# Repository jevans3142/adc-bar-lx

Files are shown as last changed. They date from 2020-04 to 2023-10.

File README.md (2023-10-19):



# ADC Theatre - Bar Lighting Controller

This repository hosts the software and hardware design for the [ADC Theatre's](https://www.adctheatre.com) bar lighting scene controller. The system is based around an ESP32 chip (using a development board typicaly found online as the DOIT board - 30 pin version, though as we are not using WiFi or Bluetooth etc the hardware could be easily adapted to another chip version) with DMX input and output, audio input for sound-to-light mode, and a remote scene set control panel.

## Features

* Provides seven reprogrammable scenes which can be faded between from the easy to use remote control panel
* DMX input for programming scenes with highest-takes-precedence merge function for operating a more complex show without recabling 
* Sound-to-light function for parties with four analogue filter channels to replicate an older system. Party functions can be enabled and disabled per scene
* Small OLED screen and menu system on the central rackmount controller for configuration
* In the event of power being disconnected the DMX input is directly connected to the output using relays to make bypass easy
* All scenes and settings are stored on an SD card

## Build

The microcontroller used is an ESP32. After standard installation of the esp-idf FreeRTOS toolchain, currently building on v5.1.1 as a stable version with the configuration included in the src folder (ie. when building do not run the idf.py set-target esp32 command as directed in the esp-idf Getting Started instructions to set up the default build config - just go straight to idf.py build)

## Hardware

PCB files in KiCAD format:
* Power supply
* Mainboard
* Sound-to-light
* Buttons (front panel)
* Remote control panel

In addition there are files for Schaeffer AG's FrontPanelDesigner application covering:
* Case including front and back panels
* Remote control panel

There are 3DM model files for two 3D printed elements: 
* A bracket to hold the OLED screen to the case frontpanel 
* A bracket to hold the SD card module to the case frontpanel

In addition to the standard components populating the PCBs one ESP32 'DOIT' style devboard, an SD card breakout module, and an OLED screen module are required, all purchased from eBay. Multiple spares are held of each item by John if required for the ADC.

## Copyright
Copyright (c) 2019-2022 John Evans and contributors.

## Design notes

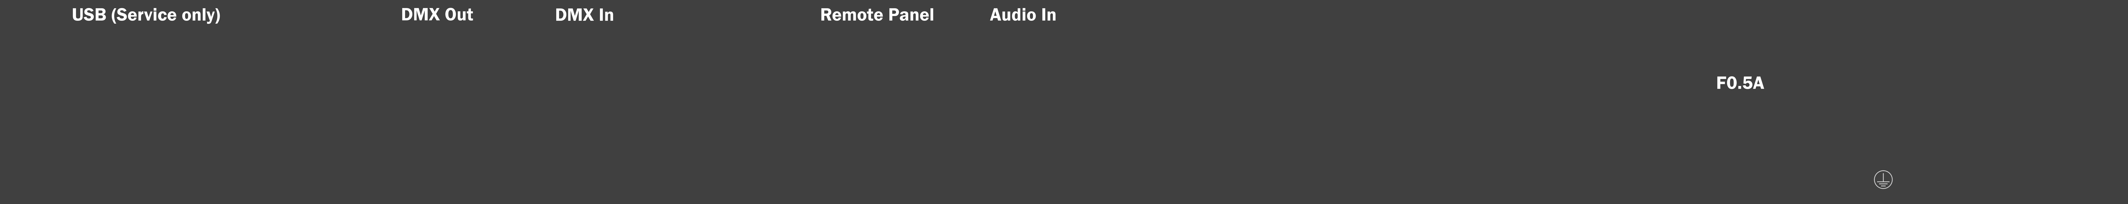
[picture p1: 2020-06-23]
hardware/case/backimg.png

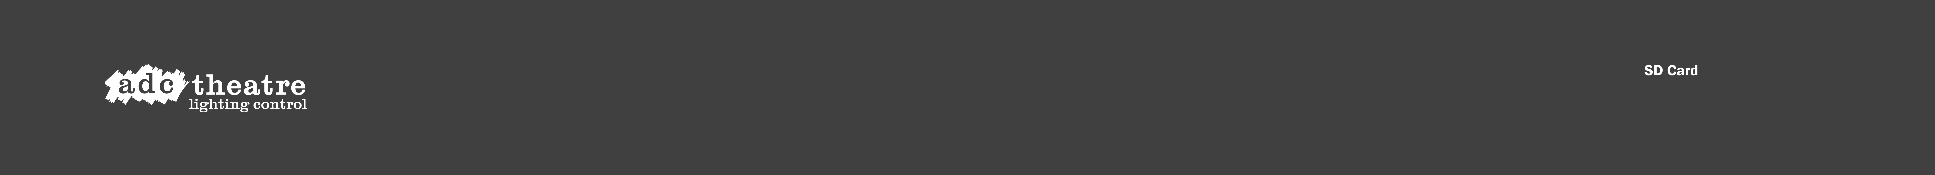
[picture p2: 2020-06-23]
hardware/case/frontimg.png

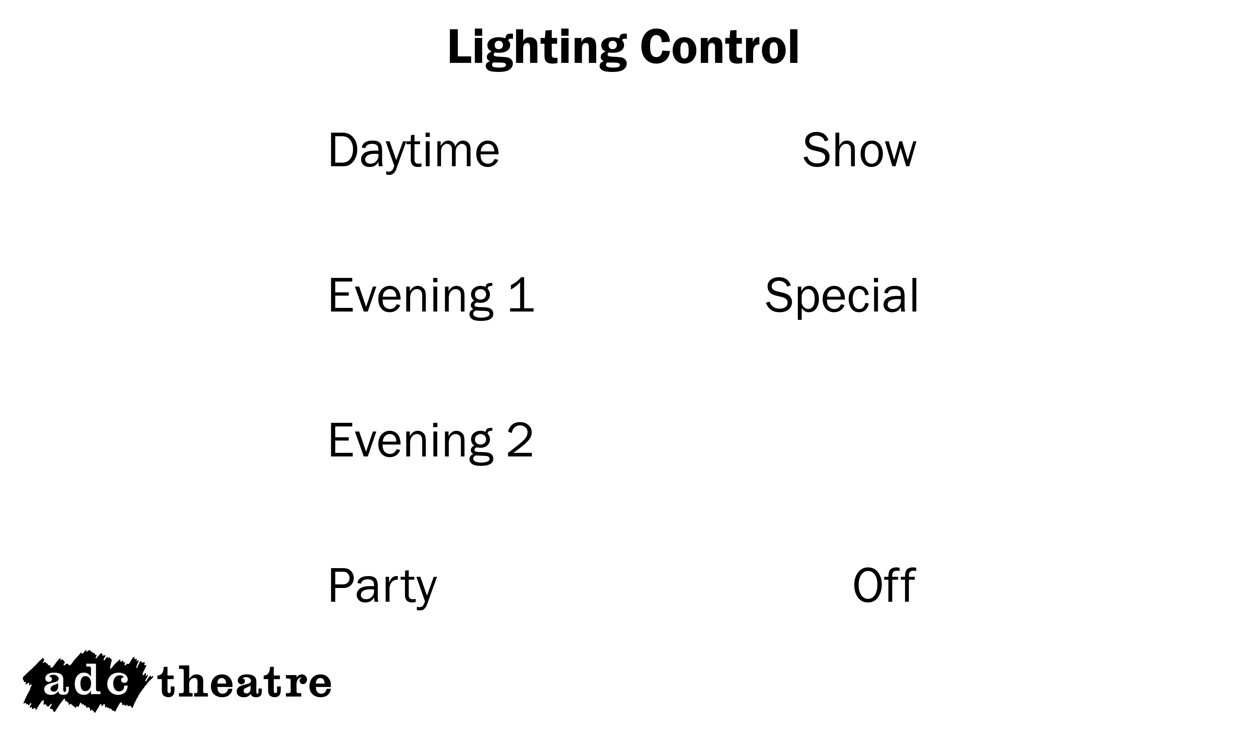
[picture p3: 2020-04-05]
hardware/control-panel-frontplate/Remotepanel.png

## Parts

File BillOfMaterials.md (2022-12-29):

# Bill of Materials - ADC Bar LX Controller

## Central Controller 
Unit is a 1U rackmount case with various PCBs inside, connectors on rear, display and user interface on front.

### Power Supply PCB
KiCAD PCB files found in hardware/psu-board
|References |Item |Package |Quantity|Value |Supplier and ref |
|---|---|---|---|---|---|
|PS1 |10W Switch mode PSU 230V->15V | |1 |RAC10-15DK/277  |RS 165-5098 |
|U1 |Switching regulator, 12V output | |1 |R-78E12-0.5 |RS 122-8230 |
|U2 |Switching regulator, 5V output | |1 |R-78E5.0-0.5 |RS 757-7239 |
|J1-J4 |4 pin 2.54mm pitch keyed connector  |2.54mm pitch |5 |Molex KK254 1x04|RS 792-2881 |
|C1,C2 |Capacitor - Electrolytic/Polarised  |2.5mm pitch  |2 |10uF |Generic |
### Main PCB
KiCAD PCB files found in hardware/main-board
|References |Item |Package |Quantity|Value |Supplier and ref |
|---|---|---|---|---|---|
|U7 |ESP32 dev board - ‘DOIT’ 30 pin type| |1 | |eBay - happybuddhatrading|
|J1, J2, J5x2 |Krone 4 pole IDC terminal | |4 | |Rapid 24-0610 |
|U3,U4 |Line Transceiver RS-422 |DIP-8 |2 |MAX485 |RS 540-2243 |
|C1,C2 |Capacitor - Unpolarised |5mm pitch |2 |470nF |Generic |
|C3 |Capacitor - Electrolytic/Polarised  |2.5mm pitch  |1 |10uF |Generic |
|J3, J4, J6, J7, J9|4 pin 2.54mm pitch keyed connector  |2.54mm pitch |5 |Molex KK254 1x04|RS 792-2881 |
|J8 |5 pin 2.54mm pitch keyed connector  |2.54mm pitch |1 |Molex KK254 1x04|RS 679-5599 |
|K1,K2 |DPDT Relay - 12V coil, non-latching | |2 | |RS 800-4441 |
|R1,R7 |0.25W resistor |10.16mm pitch|2 |470R |Generic |
|R2,R4,R5 |0.25W resistor |10.16mm pitch|3 |4.7Kohm |Generic |
|R3,R6 |0.25W resistor |10.16mm pitch|2 |120R |Generic |
|R8 |0.25W resistor |10.16mm pitch|1 |10Kohm |Generic |
|U1, U5 |DC-DC isolator 5V 1W | |2 | |RS 191-4922 |
|U2,U6 |Transistor output Optocoupler | |2 |6N137(F) |RS 625-7909 |
|- |8 pin DIP socket | |4 | |RS 674-2435 |
|- |15 pin socket (for dev board) | |2 | |RS 180-0452 |
### Sound-to-light PCB
KiCAD PCB files found in hardware/s2l-board
|References |Item |Package |Quantity|Value |Supplier and ref|
|---|---|---|---|---|---|
|C1,C2,C7,C11,C15 |Capacitor - Unpolarised |5mm pitch |5 |100nF |Generic |
|C3 |Capacitor - Unpolarised |2.5mm pitch  |1 |220pF |Generic |
|C4,C8,C12,C16 |Capacitor - Electrolytic/Polarised |1.5mm pitch  |4 |47uF |Generic |
|C5 |Capacitor - Unpolarised |5mm pitch |1 |10nF |Generic |
|C6 |Capacitor - Unpolarised |5mm pitch |1 |20nF |Generic |
|C9,C10,C13,C14,C17,C18|Capacitor - Unpolarised |5mm pitch |6 |100nF |Generic |
|D1,D3,D5,D7 |Signal diode |DO-35 |4 |1N4148 |Generic |
|D2,D4,D6,D8 |3V Zener Diode |DO-35 |4 |BZX79C3V0 |RS 544-3525 |
|J1-J3 |4 pin 2.54mm pitch keyed connector |2.54mm pitch |3 |Molex KK254 1x04|RS 792-2881 |
|R1,R8,R11,R12,R18,R27 |0.25W resistor |10.16mm pitch|6 |10Kohm |Generic |
|R2,R9 |0.25W resistor |10.16mm pitch|2 |6.8Kohm |Generic |
|R3 |0.25W resistor |10.16mm pitch|1 |3.3Kohm |Generic |
|R4 |0.25W resistor |10.16mm pitch|1 |100R |Generic |
|R5,R6 |0.25W resistor |10.16mm pitch|2 |100k |Generic |
|R7,R14,R15,R20,R25 |0.25W resistor |10.16mm pitch|5 |1Kohm |Generic |
|R10,R16,R21,R26 |0.25W resistor |10.16mm pitch|4 |2.2Kohm |Generic |
|R13,R22 |0.25W resistor |10.16mm pitch|2 |22Kohm |Generic |
|R17 |0.25W resistor |10.16mm pitch|1 |47Kohm |Generic |
|R19 |0.25W resistor |10.16mm pitch|1 |320R |Generic |
|R23 |0.25W resistor |10.16mm pitch|1 |4.7Kohm |Generic |
|R24 |0.25W resistor |10.16mm pitch|1 |220R |Generic |
|U1-U5 |Single audio op-amp |DIP-8 |5 |UA741CP |RS 305-311 |
|- |8 pin DIP socket | |5 | |RS 674-2435 |

### Buttons PCB
KiCAD PCB files found in hardware/menu-buttons
|References|Item |Package |Quantity|Value |Supplier and ref|
|---|---|---|---|---|---|
|SW1-SW4 |Tactile buttons,6x6mm,13mm high | |4 | |RS 479-1457 |
|J1 |5 pin 2.54mm pitch keyed connector|2.54mm pitch |1 |Molex KK254 1x05|RS 679-5599 |

Note that J1 is optional - wires can be soldered directly to the PCB to create a wiring harness. If so qty of 5 pin 2.54mm headers listed in 'Other' below is 1 not 2. 

### Case
The case was ordered using Front Panel Designer/Schaeffer AG. There are a number of source files for the Front Panel Designer software in hardware/case; in addition some hardware and side profile extrusions were ordered from Schaeffer at the same time. The part numbers given here are for Schaeffer's hardware parts.
- 1x Front panel (see FPD file)
- 1x Back panel (see FPD file)
- 1x Top panel (see FPD file)
- 1x Bottom panel (see FPD file)
- 2x GLGP1013 Side profiles (black anodised) - 195mm length
- 1x GGMS1122 Assembly kit ISP/B3.0-SW DIN7982 - black - consists of 8x CSK head screw 2.9mm diax9.5mm length and four rubber feet
- 1x GGWS0112 Housing bracket pack - consists of 8 L brackets
- 1x GGRB3306 Screw packet - M3x6mm CSK head machine screws 
Note that this ended up being a very, very expensive way of creating a case. There's likely some significant changes that could be made here.

### Connectors
- 1x 3D printed SD card holder - see 3dm file at hardware/sd-card-3dprint
- 1x SD card slot module - https://proto-pic.co.uk/product/sd-mmc-card-breakout-board
- 1x OLED screen module - 1.3" 128x64 OLED display I2C - eBay - karens_e-shop - https://www.ebay.co.uk/itm/282358769160
- 1x 3D printed SD card holder - see 3dm file at hardware/screen-holder-3dprint
- 1x Neutrik Powercon 20A inlet - NAC3MPXXA
- 1x Neutrik XLR-3F - NC3FDM3-L-1
- 3x 8P8C/RJ45 D type connectors - TUK D-SERIES KEYSTONE RJ45 IDC SOCKET Cat5E, tool-less, black - Canford 44-9121
- 1X USB passthrough D type - Neutrik NAUSB-W

### Other
- 1x SD card (>1MB free)
- Equipment wire and heatshrink for internal wiring
- 1.5mm Cu wiring and heatshrink for link from Powercon to PSU
- Crimp lugs for earthing of case and rear panel
- 1x Fuseholder - RS 563-784
- 1x Fuse - F0.5A LBC 5x20mm eg. RS 563-463
- 1x Powercon power cable
- Short length of audio cable (eg. Canford FST) for link from XLR to PCB
- 3x Short lengths of CAT5e cable for link from rear panel connectors to PCB
- 1x 30cm USB-A to mini-USB cable for programming port on ESP32 link to case 
- 9x 4 pin 2.54mm pitch keyed plugs to mate with PCB - Molex KK254 - RS 679-5388
- 1/2x 5 pin 2.54mm pitch keyed plugs to mate with PCB - Molex KK254 - 679-5385
- 44x (approx)  crimp contacts for connectors - Molex KK254 - RS 172-9178

## Control Panel
1x Control panel for remote control of scene states - technically this is optional
### PCB

KiCAD PCB files found in hardware/control-panel
 
|References|Item |Package |Quantity|Value |Supplier and ref|
|---|---|---|---|---|---|
|J1 |8P8C connector | |1 |8P8C |RS 331-6443 |
|SW1-SW7 |4 pin 2.54mm pitch keyed connector|2.54mm pitch |7 |Molex KK254 1x04|RS 792-2881 |
|Q1-Q7 |NPN transistor - KSP43BU |TO-92 |7 | |RS 806-4620 |
|R1-R15 |0.25W resistor |10.16mm pitch |15 |4.7Kohm |Generic |
|C1 |Capacitor - Unpolarised |5mm pitch |1 |100nF |Generic |
|C2 |Capacitor - Electrolytic/Polarised|2mm pitch |1 |10uF |Generic |
|U1 |BCD-to-decimal decoder |DIP-16 |1 |CD4028BEE4 |RS 145-0465 |
|U2 |8 line to 3 line priority encoder |DIP-16 |1 |SN74HC148 |RS 443-053 |
|U3 |3.3V voltage regulator |TO-220 |1 |LF33CV |RS 355-4128 |
|- |16 pin DIP socket |DIP-16 |2 | |RS 674-2432 |
### Other
- 7x RS Pro LED pushbuttons, panel mount, chrome, white LED - RS 111-6533
- 7x 4 pin 2.54mm pitch keyed plugs to mate with PCB - Molex KK254 - RS 679-5388
- 28x crimp contacts for connectors - Molex KK254 - RS 172-9178
- 1x Front panel - See Front Panel Designer file in hardware/control-panel-frontplate
- 4x M3x6mm panhead mouting screws (PCB to panel) 
- 2x M3.5x50mm flathead mounting screws (panel to backbox)
- Equipment wire & heatshrink for wiring of buttons to connectors
- 1 UK standard double gang backbox (in wall)
- 8P8C/RJ45 plugs and CAT5e twisted pair installation cable for link between panel and controller

## Specific spares for ADC
A number of key spares are held by John Evans for use at the ADC if required: 
- ESP32 'DOIT' dev boards of correct type
- OLED screen for controller
- All bare/upopulated PCBs 
- Various ICs: op-amps, encoder/decoders,RS485 transceivers and optoisolators 
- Relays
- SD card holder

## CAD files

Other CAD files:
hardware/sd-card-3dprint/sdcard.3dm

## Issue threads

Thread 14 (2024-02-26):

DMX Input fails to read after channel 480

jevans3142, 2024-02-26:
This is because the UART is triggering a data event every 120 bytes which is the default - during a break event the last set of bytes get lost.

See:
https://github.com/espressif/esp-idf/issues/4537

jevans3142, 2025-05-24:
And also see https://github.com/espressif/esp-idf/pull/5959

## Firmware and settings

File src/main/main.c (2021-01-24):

#include <stdio.h>
#include <string.h>
#include <stdlib.h>
#include "freertos/FreeRTOS.h"
#include "freertos/semphr.h"
#include "freertos/task.h"
#include "esp_err.h"
#include "esp_log.h"
#include "esp_system.h"
#include "nvs_flash.h"
#include "driver/gpio.h"
#include "freertos/queue.h" 

#include "main.h"
#include "dmx_io.h"
#include "screen_driver.h"
#include "button_polling.h"
#include "redraw_screen.h"
#include "scene_engine.h"
#include "storage.h"

TaskHandle_t DMX_Output_Task_Handle = NULL;
TaskHandle_t DMX_Input_Task_Handle = NULL;
TaskHandle_t Button_Poll_Task_Handle = NULL;
TaskHandle_t Display_Timeout_Task_Handle = NULL;
TaskHandle_t S2l_Meter_Refresh_Handle = NULL;

void app_main(void)
{
    vTaskDelay(100); //Pause to allow display to boot properly first
    init_sd_spi();
    setup_menu_mutexs();
    setup_scene_engine();
    setup_display_mutexs();

    //TODO: Adjust buffers and priorities 
    xTaskCreate( (TaskFunction_t) dmx_output_task, "dmx_output_task", DMX_OUTPUT_TASK_STACK_SIZE, NULL, DMX_OUTPUT_TASK_PRIO, &DMX_Output_Task_Handle);
    xTaskCreate( (TaskFunction_t) dmx_input_task, "dmx_input_task", DMX_INPUT_TASK_STACK_SIZE, NULL, DMX_INPUT_TASK_PRIO, &DMX_Input_Task_Handle);
    xTaskCreate( (TaskFunction_t) button_poll_task, "button_poll_task", BUTTON_POLL_TASK_STACK_SIZE, NULL, BUTTON_POLL_TASK_PRIO, &Button_Poll_Task_Handle);
    xTaskCreate( (TaskFunction_t) display_timeout_task, "display_timeout_task", DISPLAY_TIMEOUT_TASK_STACK_SIZE, NULL, DISPLAY_TIMEOUT_TASK_PRIO, &Display_Timeout_Task_Handle);
    
    enable_display();
    vTaskDelay(200);
    set_screen(SCREEN_MAIN_STATUS,0);
    xTaskCreate( (TaskFunction_t) s2l_meter_refresh_task, "s2l_meter_refresh_task", S2L_METER_REFRESH_TASK_STACK_SIZE, NULL, S2L_METER_REFRESH_TASK_PRIO, &S2l_Meter_Refresh_Handle);
}

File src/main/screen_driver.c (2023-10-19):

// Low-level screen driver module
//-----------------------------------

#include <stdlib.h>
#include <string.h>
#include "driver/i2c.h"
#include "esp_err.h"
#include "esp_log.h"

#include "screen_driver.h"

SemaphoreHandle_t Display_Buffer_Mutex = NULL;
//protects:
static uint8_t buffer[SH1106_LCDHEIGHT * SH1106_LCDWIDTH / 8] = { 0x0,  0x0,  0x0,  0x0,  0x0,  0x0,  0x0,  0x0,  0x0,  0x0,  0x0,  0x0,  0x0,  0x0,  0x0,  0x0,  0x0,  0x0,  0x0,  0x0,  0x0,  0x0,  0x0,  0x0,  0x0,  0x0,  0x0,  0x0,  0x0,  0x0,  0x0,  0x0,  0x0,  0x0,  0x0,  0x0,  0x0,  0x0,  0x0,  0x0,  0x0,  0x0,  0x0,  0x0,  0x0,  0x0,  0x0,  0x0,  0x0,  0x0,  0x0,  0x0,  0x0,  0x0,  0x80,  0xe0,  0xf0,  0xf8,  0xf0,  0xf0,  0xf8,  0xfc,  0xfc,  0xfc,  0xfe,  0xfe,  0xfe,  0xfc,  0xf8,  0xf8,  0xf0,  0xe0,  0x0,  0x0,  0x80,  0xc0,  0xe0,  0xf0,  0xc0,  0xc0,  0x40,  0x0,  0x0,  0x0,  0x0,  0x0,  0x0,  0x0,  0x0,  0x0,  0x0,  0x0,  0x0,  0x0,  0x0,  0x0,  0x0,  0x0,  0x0,  0x0,  0x0,  0x0,  0x0,  0x0,  0x0,  0x0,  0x0,  0x0,  0x0,  0x0,  0x0,  0x0,  0x0,  0x0,  0x0,  0x0,  0x0,  0x0,  0x0,  0x0,  0x0,  0x0,  0x0,  0x0,  0x0,  0x0,  0x0,  0x0,  0x0,  0x0,  0x0,  0x0,  0x0,  0x0,  0x0,  0x0,  0x0,  0x0,  0x0,  0x0,  0x0,  0x80,  0xc0,  0xe0,  0xf0,  0xf8,  0xfc,  0xfe,  0xe4,  0xf0,  0xe0,  0xc0,  0x80,  0x80,  0x0,  0x0,  0x0,  0x0,  0x0,  0x80,  0xc0,  0xf0,  0xf8,  0xfc,  0xfe,  0xfc,  0xfc,  0xf8,  0x10,  0x80,  0x80,  0xc0,  0xc0,  0x80,  0x0,  0x80,  0xc0,  0xe0,  0xf8,  0xfc,  0xfe,  0xff,  0xff,  0xff,  0xff,  0xff,  0xff,  0xff,  0xff,  0xff,  0x1f,  0x1f,  0x1f,  0x1f,  0x1f,  0x1f,  0x1f,  0x1f,  0x1f,  0x1f,  0x3e,  0xff,  0xff,  0xff,  0xff,  0xff,  0xff,  0xfd,  0xf8,  0xfc,  0xff,  0xff,  0xff,  0xff,  0x3e,  0x0,  0x0,  0x0,  0x80,  0xc0,  0xe0,  0xf0,  0xf8,  0xfc,  0xf0,  0xf0,  0xf8,  0xe0,  0x80,  0x0,  0x80,  0xc0,  0xc0,  0xe0,  0xf0,  0xfc,  0xfe,  0xff,  0xfc,  0xfe,  0x38,  0x8,  0x80,  0xe0,  0xf0,  0xe0,  0xe0,  0xe0,  0x80,  0x0,  0x0,  0x0,  0x0,  0x0,  0x0,  0x0,  0x0,  0x0,  0x0,  0x0,  0x80,  0xc0,  0xe0,  0xf0,  0xf0,  0xf8,  0xfc,  0xfe,  0xff,  0xff,  0xff,  0xff,  0xff,  0xff,  0xff,  0xff,  0xff,  0xff,  0xff,  0xff,  0xff,  0x7f,  0x7f,  0x3c,  0x3c,  0x3e,  0x3f,  0x3f,  0x3f,  0x3f,  0x3f,  0x7f,  0x7f,  0xff,  0xff,  0xff,  0xff,  0xff,  0xff,  0xff,  0xff,  0xff,  0xff,  0xff,  0xff,  0xff,  0xff,  0xff,  0xff,  0xff,  0xff,  0x7f,  0x7f,  0x3f,  0x3f,  0x3f,  0x3f,  0x3f,  0x3e,  0x7e,  0x7e,  0xfe,  0xfe,  0x0,  0x0,  0x0,  0x0,  0x0,  0x0,  0xff,  0xff,  0xff,  0xff,  0xff,  0xff,  0xff,  0xff,  0xff,  0xff,  0xff,  0xff,  0xff,  0xf8,  0xf8,  0xfe,  0x7f,  0x7f,  0x3f,  0x3f,  0x3f,  0x3f,  0x3f,  0x3f,  0x3f,  0x7f,  0x7f,  0xff,  0xff,  0xff,  0xff,  0xff,  0xff,  0xff,  0xff,  0xff,  0xff,  0xff,  0xff,  0xfc,  0xfe,  0xff,  0xff,  0xff,  0xff,  0x3f,  0xf,  0x3,  0x0,  0x0,  0x0,  0x0,  0x0,  0x0,  0x0,  0x10,  0x7c,  0x7e,  0xff,  0xff,  0xff,  0xff,  0xff,  0xff,  0xff,  0xff,  0xff,  0xff,  0xff,  0xff,  0xff,  0xff,  0xff,  0xff,  0xff,  0xff,  0xff,  0xc3,  0x80,  0x0,  0x0,  0x0,  0x0,  0x86,  0xfe,  0xfe,  0x7e,  0x7c,  0x7c,  0x38,  0x0,  0x0,  0x0,  0x0,  0x3,  0xff,  0xff,  0xff,  0xff,  0xff,  0xff,  0xff,  0xff,  0xff,  0xff,  0xff,  0x1f,  0x7,  0x1,  0x0,  0x0,  0x0,  0x80,  0xf0,  0xf8,  0xfc,  0xfc,  0xfc,  0xf8,  0xf8,  0xf0,  0xc1,  0x0,  0x0,  0x0,  0x0,  0x0,  0x0,  0xff,  0xff,  0xff,  0xff,  0xff,  0xff,  0xff,  0xff,  0xff,  0xff,  0x3f,  0xf,  0x3,  0x1,  0x0,  0x0,  0x0,  0xe0,  0xf8,  0xfc,  0xfc,  0xfc,  0xfc,  0xfc,  0xc,  0x4,  0x0,  0x0,  0x0,  0x1,  0x87,  0xff,  0xff,  0xff,  0xff,  0xff,  0xff,  0xff,  0xff,  0xff,  0xff,  0xff,  0xff,  0xff,  0xff,  0xfe,  0xfe,  0xbf,  0x8c,  0xc0,  0xe0,  0x78,  0x3c,  0x18,  0x8,  0x0,  0x0,  0x0,  0x0,  0x1,  0x0,  0x0,  0x83,  0xf3,  0xff,  0xff,  0xff,  0xff,  0xff,  0xff,  0xff,  0xff,  0xff,  0xff,  0xff,  0xff,  0xf,  0x7,  0x3,  0x3,  0x1,  0x1,  0x0,  0xe0,  0xf0,  0xf8,  0xf8,  0xfc,  0x7c,  0xc,  0x0,  0x0,  0x0,  0x0,  0x0,  0xff,  0xff,  0xf,  0xf,  0xf,  0xf,  0xff,  0xff,  0xff,  0xff,  0xff,  0xc0,  0x0,  0x0,  0x0,  0x0,  0x0,  0x7,  0x3f,  0xff,  0xff,  0xff,  0xff,  0xff,  0x7f,  0x3f,  0xf,  0x0,  0x0,  0x0,  0x0,  0x0,  0x0,  0xff,  0xff,  0xff,  0xff,  0xff,  0xff,  0xff,  0xff,  0xff,  0xff,  0xe0,  0x80,  0x0,  0x0,  0x0,  0x0,  0x0,  0x1f,  0x7f,  0xff,  0xff,  0xff,  0xff,  0xff,  0xff,  0x7f,  0x1e,  0x6,  0x6,  0x7,  0xc7,  0xff,  0xff,  0xff,  0xff,  0xff,  0xff,  0xff,  0xff,  0xff,  0xff,  0xff,  0xff,  0xff,  0x7f,  0x3f,  0x1f,  0x7,  0x3,  0x1,  0x0,  0x0,  0x0,  0x0,  0x0,  0x0,  0x0,  0x0,  0x80,  0xe0,  0xf8,  0xfe,  0xff,  0xff,  0xff,  0xff,  0xff,  0xff,  0xff,  0xff,  0xff,  0xff,  0xff,  0xff,  0xff,  0xff,  0xfc,  0xf8,  0xf0,  0xf0,  0xe0,  0xe0,  0xe0,  0xe0,  0xe1,  0xf1,  0xf1,  0xf0,  0xf8,  0xfc,  0xf8,  0xf0,  0xf0,  0xe0,  0xe0,  0xe0,  0xe1,  0xf0,  0xf0,  0xf8,  0xfe,  0xff,  0xff,  0xff,  0xff,  0xff,  0xff,  0xff,  0xfc,  0xf8,  0xf8,  0xf0,  0xf0,  0xe0,  0xe0,  0xe0,  0xe0,  0xe0,  0xf0,  0xf0,  0xf8,  0xfc,  0xf0,  0xf0,  0xf0,  0xf0,  0xf0,  0xf0,  0xf0,  0xf1,  0xf1,  0xf1,  0xff,  0xff,  0xff,  0xff,  0xff,  0xff,  0xff,  0xff,  0xfe,  0xfc,  0xf8,  0xf8,  0xf0,  0xf0,  0xe0,  0xe0,  0xe0,  0xe1,  0xe1,  0xe0,  0xf0,  0xf0,  0xf8,  0xf8,  0xfc,  0xfe,  0xff,  0xff,  0xff,  0xff,  0xff,  0xff,  0xff,  0xff,  0xff,  0x7f,  0x3f,  0xf,  0x3,  0x1,  0x0,  0x0,  0x0,  0x0,  0x0,  0x0,  0x0,  0x0,  0x0,  0x0,  0x0,  0x0,  0x8,  0xe,  0xf,  0x1f,  0x3f,  0x1f,  0xf,  0xcf,  0xff,  0xff,  0xff,  0xff,  0xff,  0xff,  0x7f,  0x1f,  0xf,  0x3,  0x3,  0x3,  0x1f,  0x1f,  0x7f,  0x7f,  0x7f,  0x3f,  0x1f,  0x9f,  0xff,  0xff,  0xff,  0xff,  0xff,  0xff,  0x7f,  0x1f,  0xf,  0x3,  0x1,  0x0,  0x0,  0x3,  0x3,  0x7,  0xf,  0x1f,  0x1f,  0x3f,  0x3f,  0x7f,  0xff,  0xff,  0x7f,  0xff,  0x3f,  0xf,  0xf,  0x1f,  0x1f,  0x3f,  0x7f,  0x7f,  0xff,  0xff,  0xff,  0xff,  0xff,  0xff,  0xff,  0xff,  0xff,  0xff,  0xff,  0xff,  0x3f,  0x1f,  0x1f,  0x7f,  0x3f,  0x1f,  0x3f,  0xff,  0xff,  0xff,  0xff,  0xff,  0xff,  0xff,  0xff,  0xff,  0xff,  0xff,  0xff,  0x3f,  0xf,  0xf,  0xf,  0x3f,  0x3f,  0x3f,  0x7f,  0x3f,  0x3f,  0x7f,  0x7f,  0x7f,  0xff,  0xff,  0x1f,  0x7,  0x1,  0x0,  0x0,  0x0,  0x0,  0x0,  0x0,  0x0,  0x0,  0x0,  0x0,  0x0,  0x0,  0x0,  0x0,  0x0,  0x0,  0x0,  0x0,  0x0,  0x0,  0x0,  0x0,  0x0,  0x0,  0x0,  0x3,  0x1,  0x1,  0x1,  0x3,  0x0,  0x0,  0x0,  0x0,  0x0,  0x0,  0x0,  0x0,  0x0,  0x0,  0x0,  0x0,  0x0,  0x2,  0x3,  0x3,  0xf,  0x1f,  0x7,  0x3,  0x0,  0x0,  0x0,  0x0,  0x0,  0x0,  0x0,  0x0,  0x0,  0x0,  0x0,  0x0,  0x0,  0x0,  0x0,  0x0,  0x0,  0x0,  0x0,  0x0,  0x0,  0x0,  0x0,  0x0,  0x0,  0x0,  0x0,  0x0,  0x0,  0x1,  0x0,  0x1,  0x1,  0x7,  0x7,  0xf,  0x1f,  0x1f,  0x7,  0x3,  0x0,  0x0,  0x0,  0x0,  0x0,  0x0,  0x0,  0x0,  0x0,  0x0,  0x1,  0x1,  0x3,  0x3,  0x7,  0xf,  0xf,  0xf,  0x3,  0x0,  0x0,  0x0,  0x0,  0x0,  0x0,  0x0,  0x0,  0x0,  0x0,  0x0,  0x0,  0x0,  0x0,  0x0,  0x0,  0x0,  0x0,  0x0,  0x0,  0x0,
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

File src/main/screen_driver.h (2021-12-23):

// Low-level screen driver module
//-----------------------------------

#ifndef SCREEN_DRIVER_H_INCLUDED
#define SCREEN_DRIVER_H_INCLUDED

#include "freertos/FreeRTOS.h"

#define PIN_I2C_SCL (22)               
#define PIN_I2C_SDA (21)              
#define I2C_NUM I2C_NUM_0        
#define I2C_FREQ 400000     
#define I2C_TX_BUFFER 0                     
#define I2C_RX_BUFFER 0                          
#define I2C_DISPLAY_ADDRESS 0x3c
#define I2C_WRITE_BIT I2C_MASTER_WRITE  
#define I2C_ACK_CHECK_EN 0x1            

#define SH1106_SETLOWCOLUMN 0x00
#define SH1106_SETHIGHCOLUMN 0x10
#define SH1106_SETSTARTLINE 0x40
#define SH1106_LCDWIDTH 128
#define SH1106_LCDHEIGHT 64

//Pixel type, fill type
#define BLACK 0
#define WHITE 1
#define INVERT 2
#define LEAVE 3

#define NORMAL_SIZE 0
#define DOUBLE_SIZE 1

void setup_display_mutexs(void);
void refresh_display(void);
void enable_display(void);
void reenable_display(void);
void disable_display(void);
void clear_display(void);
void draw_pixel(uint8_t x, uint8_t y, uint8_t type);
void draw_line(uint8_t x1, uint8_t y1, uint8_t x2, uint8_t y2, uint8_t type);
void draw_rect(uint8_t x1, uint8_t y1, uint8_t x2, uint8_t y2, uint8_t outline, uint8_t fill);
void draw_string(uint8_t x, uint8_t y, char* s, uint8_t scaling, uint8_t type);

#endif

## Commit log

2019-11-02 Add basic DMX output
    Basic DMX output UART code from empty buffer - to be linked to scene output
2019-11-09 Initial display driver
    Boilderplate display driver code - static image for now
2019-11-10 Add basic string draw funcs
    Basic string print function in normal and double size - only support in white for now - also boilerplate for circle print function
2019-12-05 Button polling task base
2019-12-23 Add initial displays
    Individual screens using the screen driver core; also alter screen driver core to make redraws neater
2019-12-23 Menu buttons polling boilerplate
    First stab at debouncing code; no actions programmed yet
2019-12-24 Alter button pin assignments
    GPIO2 seems INOP or unusable - built in LED funnyness?
2019-12-25 Basic menu structure
    Buttons work for navigating menus; call correct screens (not yet written)
    [button_polling.c, redraw_screen.c]
2019-12-26 Fix screen refresh
    This seems to fix screen refresh issue - not sure why I2C did not play ball when previously trying speeds. I2C functions still badly laid out but can be dealt with later; works for now.
    [main.c, redraw_screen.c, screen_driver.h]
2019-12-28 Add scene engine boilerplate + remote scene control panel interface
    BCD in and out to remote encoder/decoder chips in control panel for LEDs and buttons
2019-12-29 Clean up button polling code
    Pointerise loop content into a subfunction
2019-12-29 Minor code style corrections
    [dmx_io.c]
2019-12-29 Further button polling cleanup
    Delete unneeded loop code
2019-12-30 Menu buttons PCB rev A design and schematic
    Schematic and draft rev A PCB layout for front panel menu buttons - TBC once components ordered
    [menu-buttons.kicad_pcb, menu-buttons.sch]
2020-01-02 Threadsafe display buffer access
    Add buffer mutex to all direct access to display buffer, and remove unused function prototype for circle drawing
2020-01-02 Update menu buttons PCB
    Smaller mounting holes, correct Molex header
    [menu-buttons.kicad_pcb]
2020-01-03 Remove draw_circle function prototype
    Should have been removed in last commit
2020-02-07 Remote Control Panel PCB
    Rev A PCB as ordered
    [control-panel.kicad_pcb, control-panel.sch]
2020-02-07 Menu buttons PCB update
    Update to Rev A PCB as ordered
    [menu-buttons.kicad_pcb]
2020-04-12 PSU PCB
    Add schematic and board files for PSU
    [psu-board.kicad_pcb, psu-board.sch]
2020-04-12 Main board initial
    Add start of motherboard schematic and PCB
    [main-board.kicad_pcb, main-board.sch]
2020-04-12 Alter remote panel PCB pins
    Alter pins to align with updated schematic
2020-05-10 Startup delay
    Add startup delay before activating screen to account for screen powering up slower than ESP32
2020-05-16 Tidy up button polling
    Add extra redraw calls to button presses as required, visual tidy up to button debounce code
2020-05-16 Fix double scene set bug
    Fix bug where mutex was not released when setting to the already set scene
    [scene_engine.c]
2020-05-16 Ensure only dimmer frames are sent
    First number will only be 0 (start code)
2020-05-17 Sound to Light framework
    Basic S2L sampling added; properties and data not yet linked to UI
2020-05-17 Fix bug drawing currently edited value on UI screens
    Wasn't rendering strings correctly
    [redraw_screen.c]
2020-05-17 Fix DMX output task call
    Should have been in earlier commit
    [dmx_io.c]
2020-05-23 Scene recording and SD card storage
    Add module to save and load scenes to SD card. Add power on scene restore from SD card, and functions to record scene to SD card as well as into working memory. Also add 'special' scene record functi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
2020-05-23 Sound to light schematic
    First draft of sound to light board schematic
    [s2l-board.kicad_pcb, s2l-board.sch]
2020-05-26 Sound to light board completed, PSU board completed
    Rev As as ordered
    [main-board.sch, psu-board.kicad_pcb, s2l-board.sch]
2020-06-04 Motherboard Rev A
    PCB as ordered
    [main-board.sch]
2020-06-23 Case Rev A
    As ordered
2020-06-23 PCB updates
    Correction to motherboard R value, update of buttons PCB to rev B as ordered to go in case with reduced clearance
    [main-board.kicad_pcb, main-board.sch, menu-buttons.kicad_pcb]
2020-10-24 Fixes - Fix double height text
    [button_polling.c, main.c, screen_driver.c]
2020-10-24 Fix main screen spacing
    Deconflict text and icons by changing double size text
    [redraw_screen.c, screen_driver.c]
2020-10-24 Fix - main screen rectangle
    Main screen rectangle fix (actually the line function was wrong)
    [redraw_screen.c, screen_driver.c]
2020-10-27 Fix - Rect draw filling bug
    When drawing a rectangle of zero width or height it would overrun the page
    [screen_driver.c]
2021-01-23 Add 3D printed elements
    Add Rhino files for 3D printed SD card holder and screen holder
    [sdcard.3dm]
2021-01-23 Update UART enums
    Fix UART enums that were removed in latest version of esp-idf
    [dmx_io.c]
2021-01-24 Fix SD card access
    Update SD card routines to align with new API calls in esp-idf 4.2 - fixes the build
    [main.c, scene_engine.c, storage.c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]
2021-01-24 Fix crashing on scene change
    Fixes crashes where the scene number mutex was taken for too long during the scene engine calculation, leading to retrieving a NULL scene number sometimes and crashing the display thread
    [scene_engine.c, storage.c]
2021-01-24 Fix pointer compile warnings
    Various compile warnings about pointer types
    [button_polling.c, main.c, scene_engine.c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]
2021-12-23 Fix compile warning in screen driver function call
    [screen_driver.c, screen_driver.h]
2022-09-12 Fix i2c bug introduced in esp_idf 4.3
    Needs extra flag set... breaking change in 4.3 grumble grumble
    [screen_driver.c]
2022-12-27 Begin bill of materials
2022-12-27 Make bill of materials markdown file
2022-12-27 Fix bom rendering
    maybe
2022-12-29 Finish bill of materials
2024-02-25 Reduce S2L meters appearing on menu randomly
    Mutex for scene number was being taken for too long when changing screen; should fix most instances - still one race condition left (see #13 comments)
    Also correct some indentation
    [dmx_io.c, redraw_screen.c, scene_engine.c]
